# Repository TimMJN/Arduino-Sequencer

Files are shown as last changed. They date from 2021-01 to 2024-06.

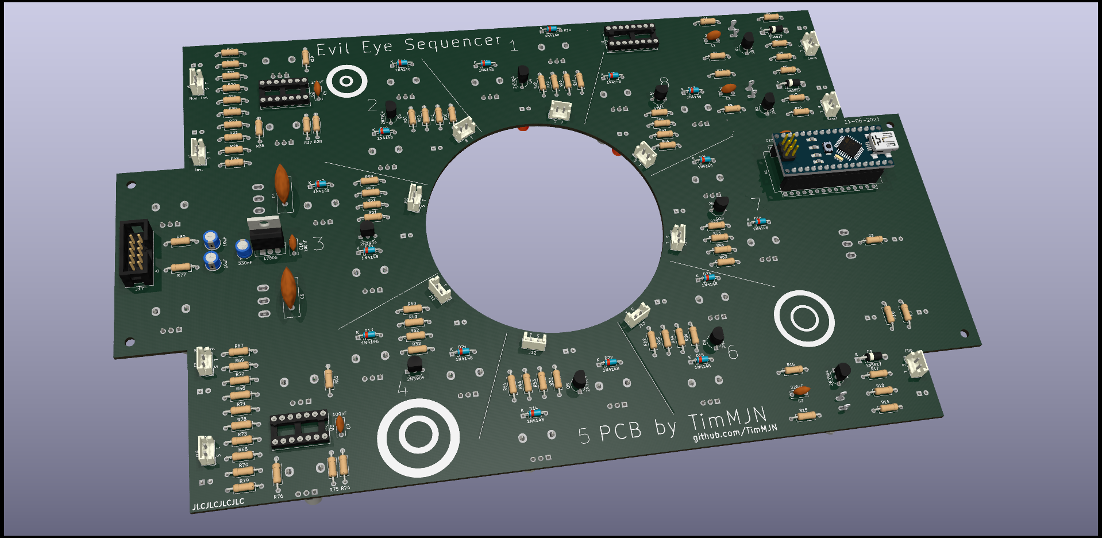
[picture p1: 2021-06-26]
images/arduino_sequencer_render_back.png

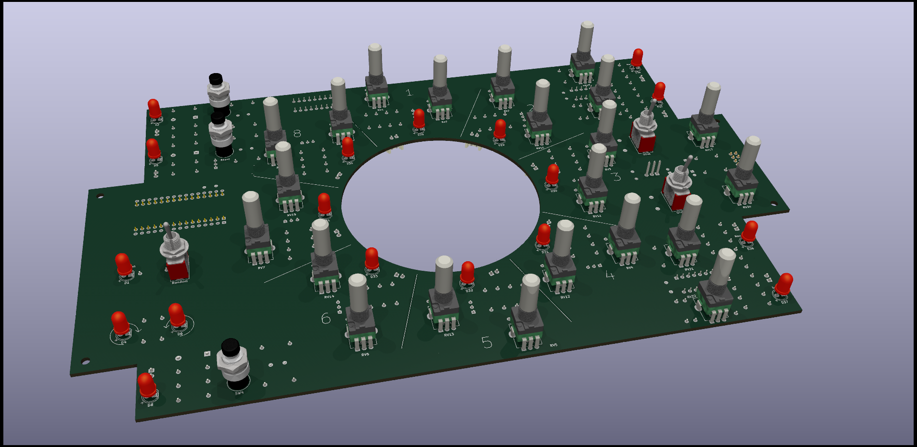
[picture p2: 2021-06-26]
images/arduino_sequencer_render_front.png

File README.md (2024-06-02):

# Arduino Sequencer
This projects contains schematics and firmware for a step sequencer compatible with Eurorack and Kosmo modular synthesizers, based on an Arduino Nano. This is a DIY project, suitable for beginners, although a general knowledge of electronics, basic tools and skills are required to build this sequencer. The schematics presented here feature:

- 8 steps, 2 voices
- Clock/reset/flip direction inputs
- Random sequence switch
- Buffered gate outputs per step
- Buffered CV outputs per voice
- Scale/offset controls
- Glide controls

Any builder is encouraged to experiment and make changed to the project to suit their needs. By the use of 74HC595 Serial-In-Parallel-Out shift registers to drive the step signals, this sequencer can be easily extended to 16, 32, 64 or even more steps. Similarly, additional voice can be easily added. I'll keep updating the project and documentation as I go.

A [short demonstration](https://youtu.be/yhleVjD8cbQ) is available in YouTube. View the [schematic](schematic+BOM/arduino_sequencer.pdf) and [bill of materials](https://htmlpreview.github.io/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) on this repository.

# Frequently Asked Questions
## The build
#### Do you have PCBs / panels available?
A PCB design for Kosmo format is available, along with a panel drill guide. I might have some PCBs available, please get in touch. However, it is also possible to build this design on perfboard/stripboard. I want to encourage any builder to come up with their own panel layout, make whatever feels natural to them. If you document your work, I'll be happy to add it here for future reference.

#### How to I add more steps?
Simply copy the main sequencer section as many times as you like. The connections between the 74HC595s are noted in the schematic. The latch and clock pins simply connect together, the serial out of each register connects to the serial in of the next. In the code, change the value of `N_STEPS` and voila!

#### How to I add more voices?
Copy the row of potentiometers/diodes in the main sequencer section as many times as you like. Don't forget to also copy the asociated output circuitry!

#### Can I leave out the gate buffers?
Yes you can. It would be best practice the keep them, but they could be replaced by just a protection diode (e.g. 1N1418).

#### Can I leave out the offset/scale/glide?
I would advice against using no buffering at all, but you could replace this section with just a unity gain buffer. It's also possible to leave out only the glide components, in which case you can also do without the non-inverting buffer behind it.

#### Can I leave out the input protection?
This I would strongly advice against. It's very easy to fry the Arduino by plugging in the wrong signal. You could simplify to a voltage clamp using two Schottky diodes, but I don't see the point in not doing it properly. If you do go with that option, don't forget to change to input logic to track rising instead of falling edges, as the current set-up inverts the inputs.

#### Can I leave out the randomise switch?
Yes, just simply don't include it.

## The code
#### Why don't you use `shiftOut`?
The serial output code I wrote here does the exact same thing as `shiftOut`. I only adapted it to output any number of steps, as the standard 8 bits by `shiftOut`.

#### What's this `interrupt` business?
This allows that Arduino to stop whatever it's doing when it receives a pulse on the clock input and update to the next step. That means that the polling of the other input pins will never slow down the progressing to the next step. Neat!

## The patch
#### Why can't I change the sequence length?
You can, simply patch the gate of the last step to the reset input.

#### Why can't I set a back-and-forth pattern?
You can, simply patch one or two of the gates to the flip input.

# License
All designs in this repository are released under GPL-3.0 licence. Feel free to use and adapt them to your heart's desire. I only ask to refrain from mass-production and commercialisation of PCBs/modules, as I rely on PCB sales for funding new module designs. If you use (parts of) my designs in your own modules, please credit me on your schematics and PCBs to help users find the original creator. I call upon your good conscience to make fair use of my work shared here.

# Support
If you like the resources I have made available here, and wish to support the development of new modules, feel free to buy me a few components through a small donation. I mainly design modules for fun, but you probably already know it can be a costly endeavour. All small contributions help me, thank you very much!



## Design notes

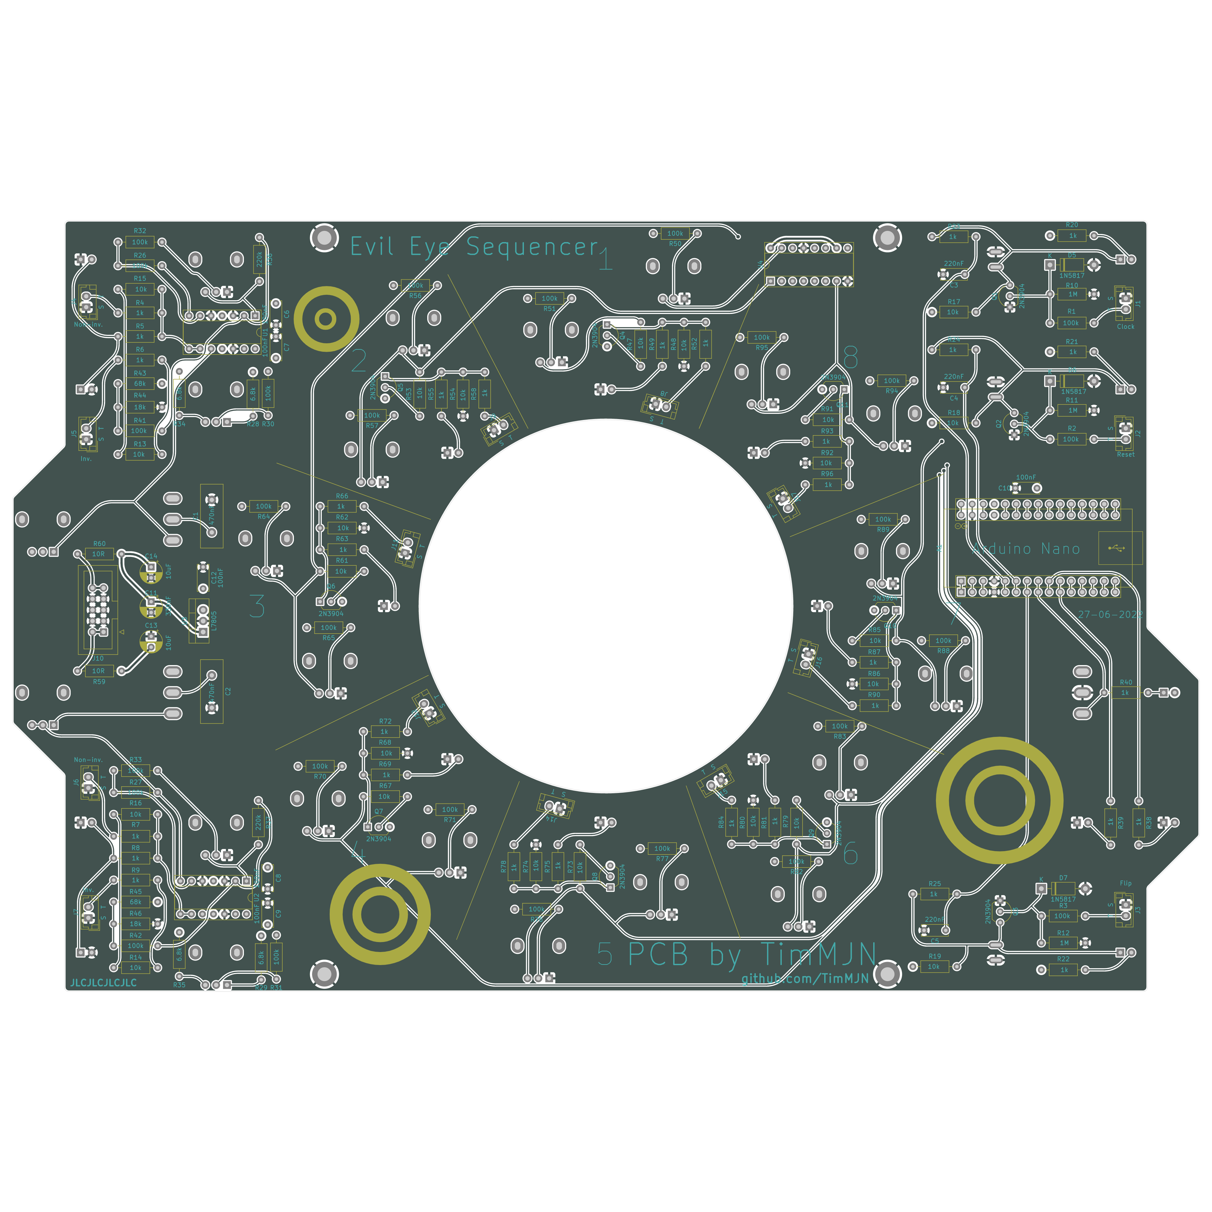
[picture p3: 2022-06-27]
PCB/arduino_sequencer-PCB_front.png

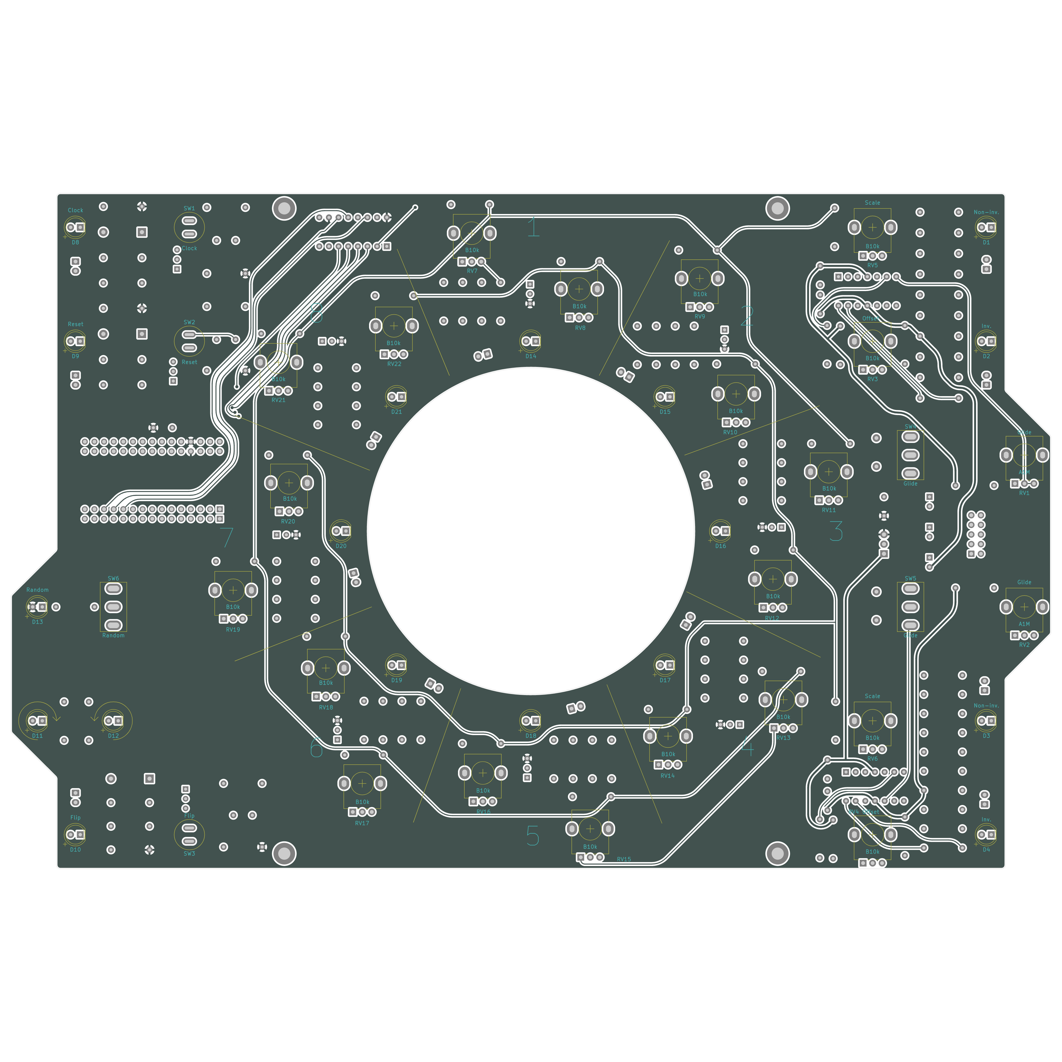
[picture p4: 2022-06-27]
PCB/arduino_sequencer-PCB_back.png

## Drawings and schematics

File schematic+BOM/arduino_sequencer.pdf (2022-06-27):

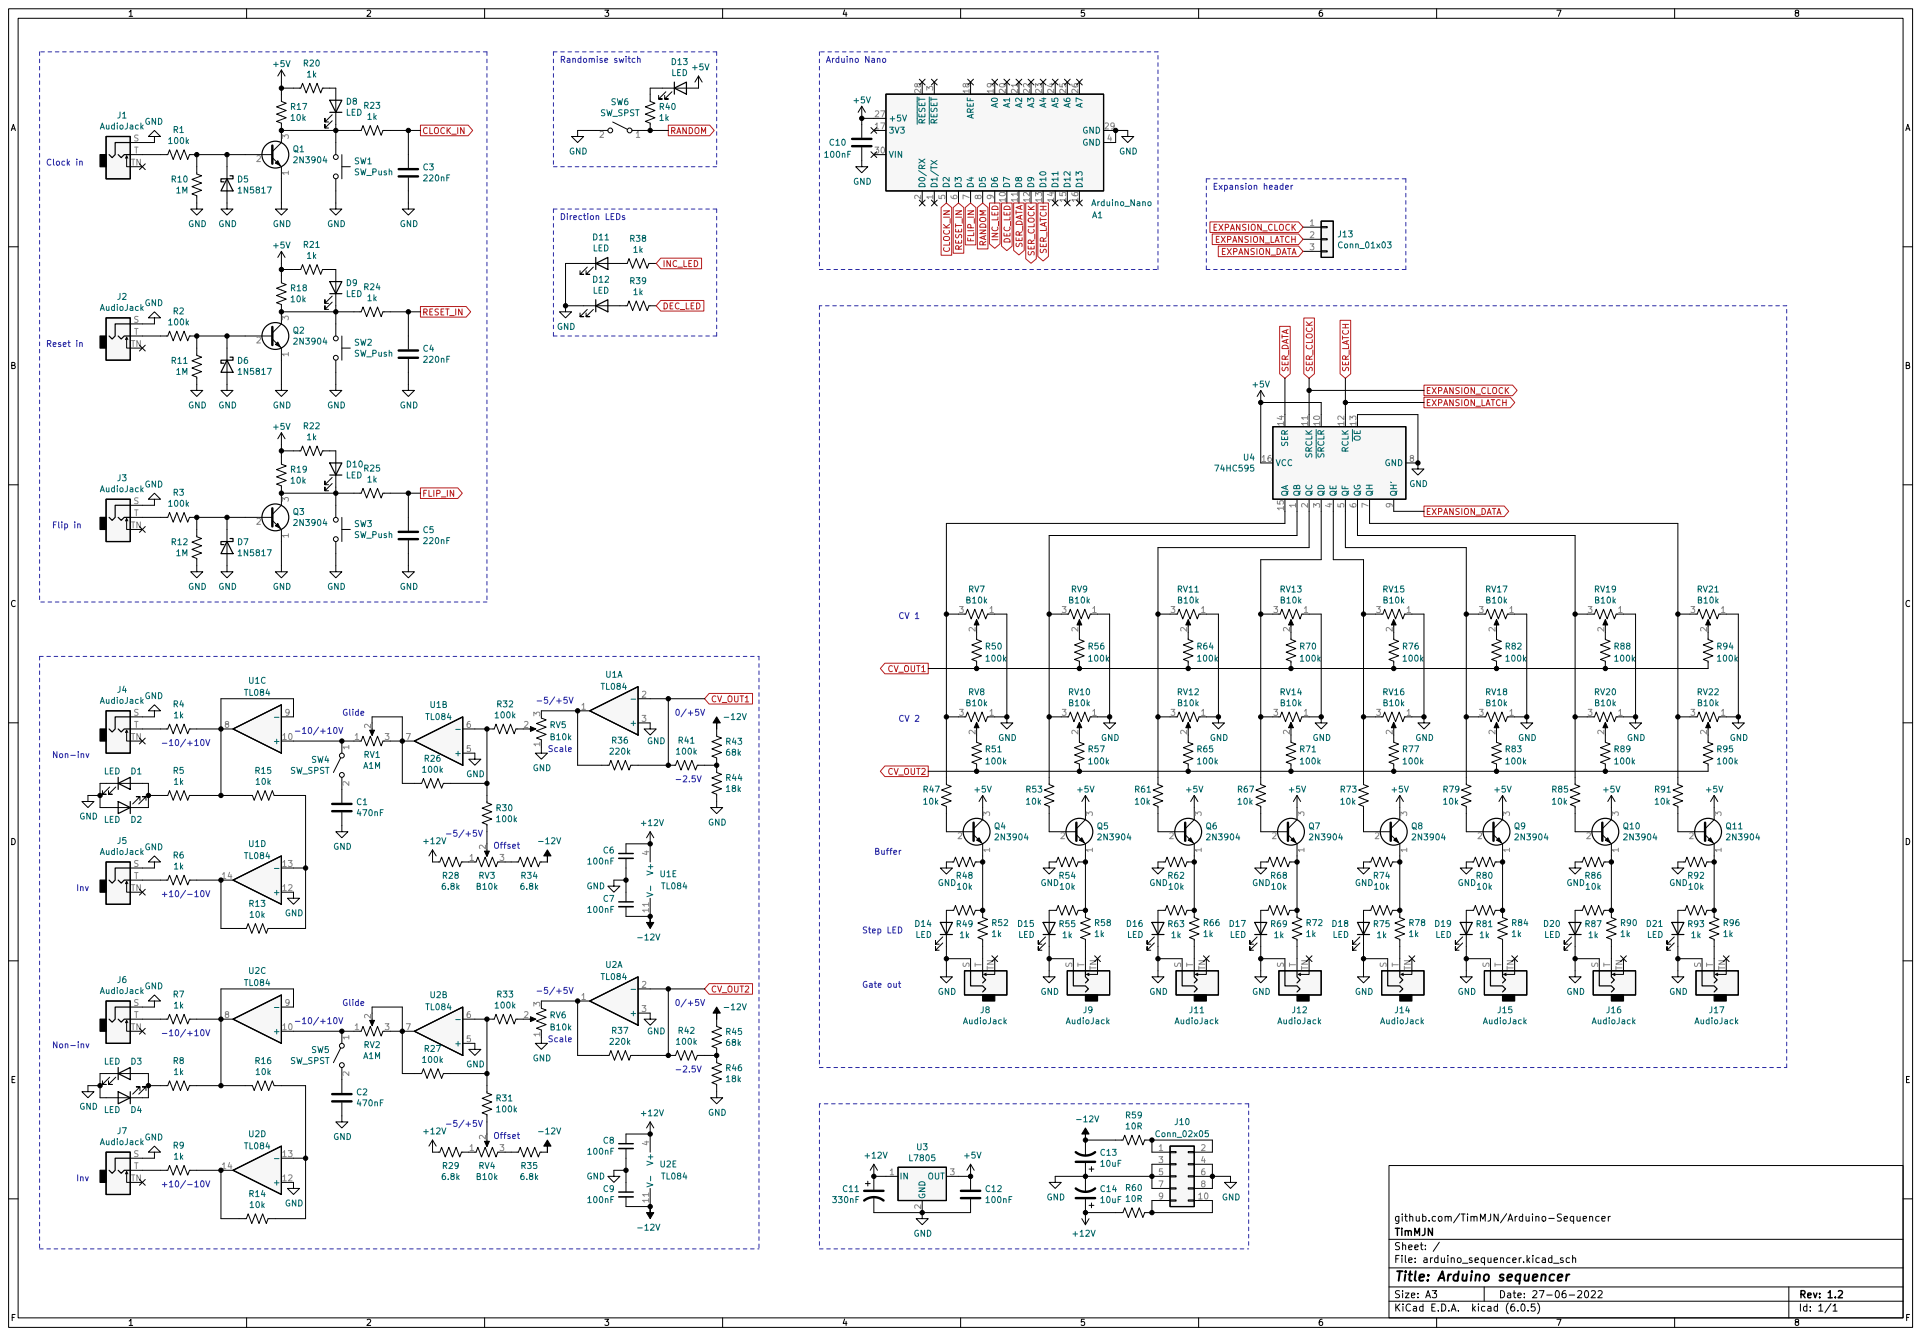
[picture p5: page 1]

Expansion header Non-inv

1 ~{SRCLR}10 SRCLK 11 RCLK 12 ~{OE}13 SER 14 QA 15 VCC 16 QC

github.com/TimMJN/Arduino-Sequencer D15

Id: 1/1 Title: Arduino sequencer

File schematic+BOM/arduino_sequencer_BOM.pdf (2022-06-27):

Arduino Sequencer | Rev: 1.4
TimMJN | 27-06-2022

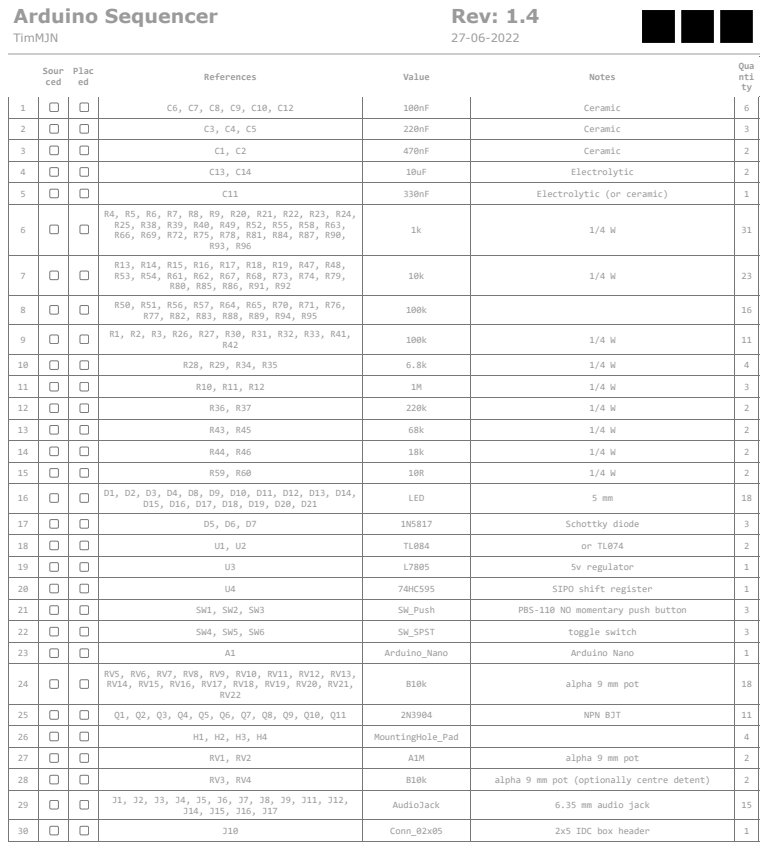
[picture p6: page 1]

Sour ced | Plac ed | References | Value | Notes | Qua nti ty

1 | | | C6, C7, C8, C9, C10, C12 | 100nF | Ceramic | 6

2 | | | C3, C4, C5 | 220nF | Ceramic | 3

3 | | | C1, C2 | 470nF | Ceramic | 2

4 | | | C13, C14 | 10uF | Electrolytic | 2

5 | | | C11 | 330nF | Electrolytic (or ceramic) | 1
6 | | | R4, R5, R6, R7, R8, R9, R20, R21, R22, R23, R24, R25, R38, R39, R40, R49, R52, R55, R58, R63, R66, R69, R72, R75, R78, R81, R84, R87, R90, R93, R96 | 1k | 1/4 W | 31

15 | | | R59, R60 | 10R | 1/4 W | 2
16 | | | D1, D2, D3, D4, D8, D9, D10, D11, D12, D13, D14, D15, D16, D17, D18, D19, D20, D21 | LED | 5 mm | 18

17 | | | D5, D6, D7 | 1N5817 | Schottky diode | 3

19 | | | U3 | L7805 | 5v regulator | 1

20 | | | U4 | 74HC595 | SIPO shift register | 1

21 | | | SW1, SW2, SW3 | SW_Push | PBS-110 NO momentary push button | 3

22 | | | SW4, SW5, SW6 | SW_SPST | toggle switch | 3

23 | | | A1 | Arduino_Nano | Arduino Nano | 1
24 | | | RV5, RV6, RV7, RV8, RV9, RV10, RV11, RV12, RV13, RV14, RV15, RV16, RV17, RV18, RV19, RV20, RV21, RV22 | B10k | alpha 9 mm pot | 18

25 | | | Q1, Q2, Q3, Q4, Q5, Q6, Q7, Q8, Q9, Q10, Q11 | 2N3904 | NPN BJT | 11

26 | | | H1, H2, H3, H4 | MountingHole_Pad | | 4

27 | | | RV1, RV2 | A1M | alpha 9 mm pot | 2

28 | | | RV3, RV4 | B10k | alpha 9 mm pot (optionally centre detent) | 2
29 | | | J1, J2, J3, J4, J5, J6, J7, J8, J9, J11, J12, J14, J15, J16, J17 | AudioJack | 6.35 mm audio jack | 15

30 | | | J10 | Conn_02x05 | 2x5 IDC box header | 1

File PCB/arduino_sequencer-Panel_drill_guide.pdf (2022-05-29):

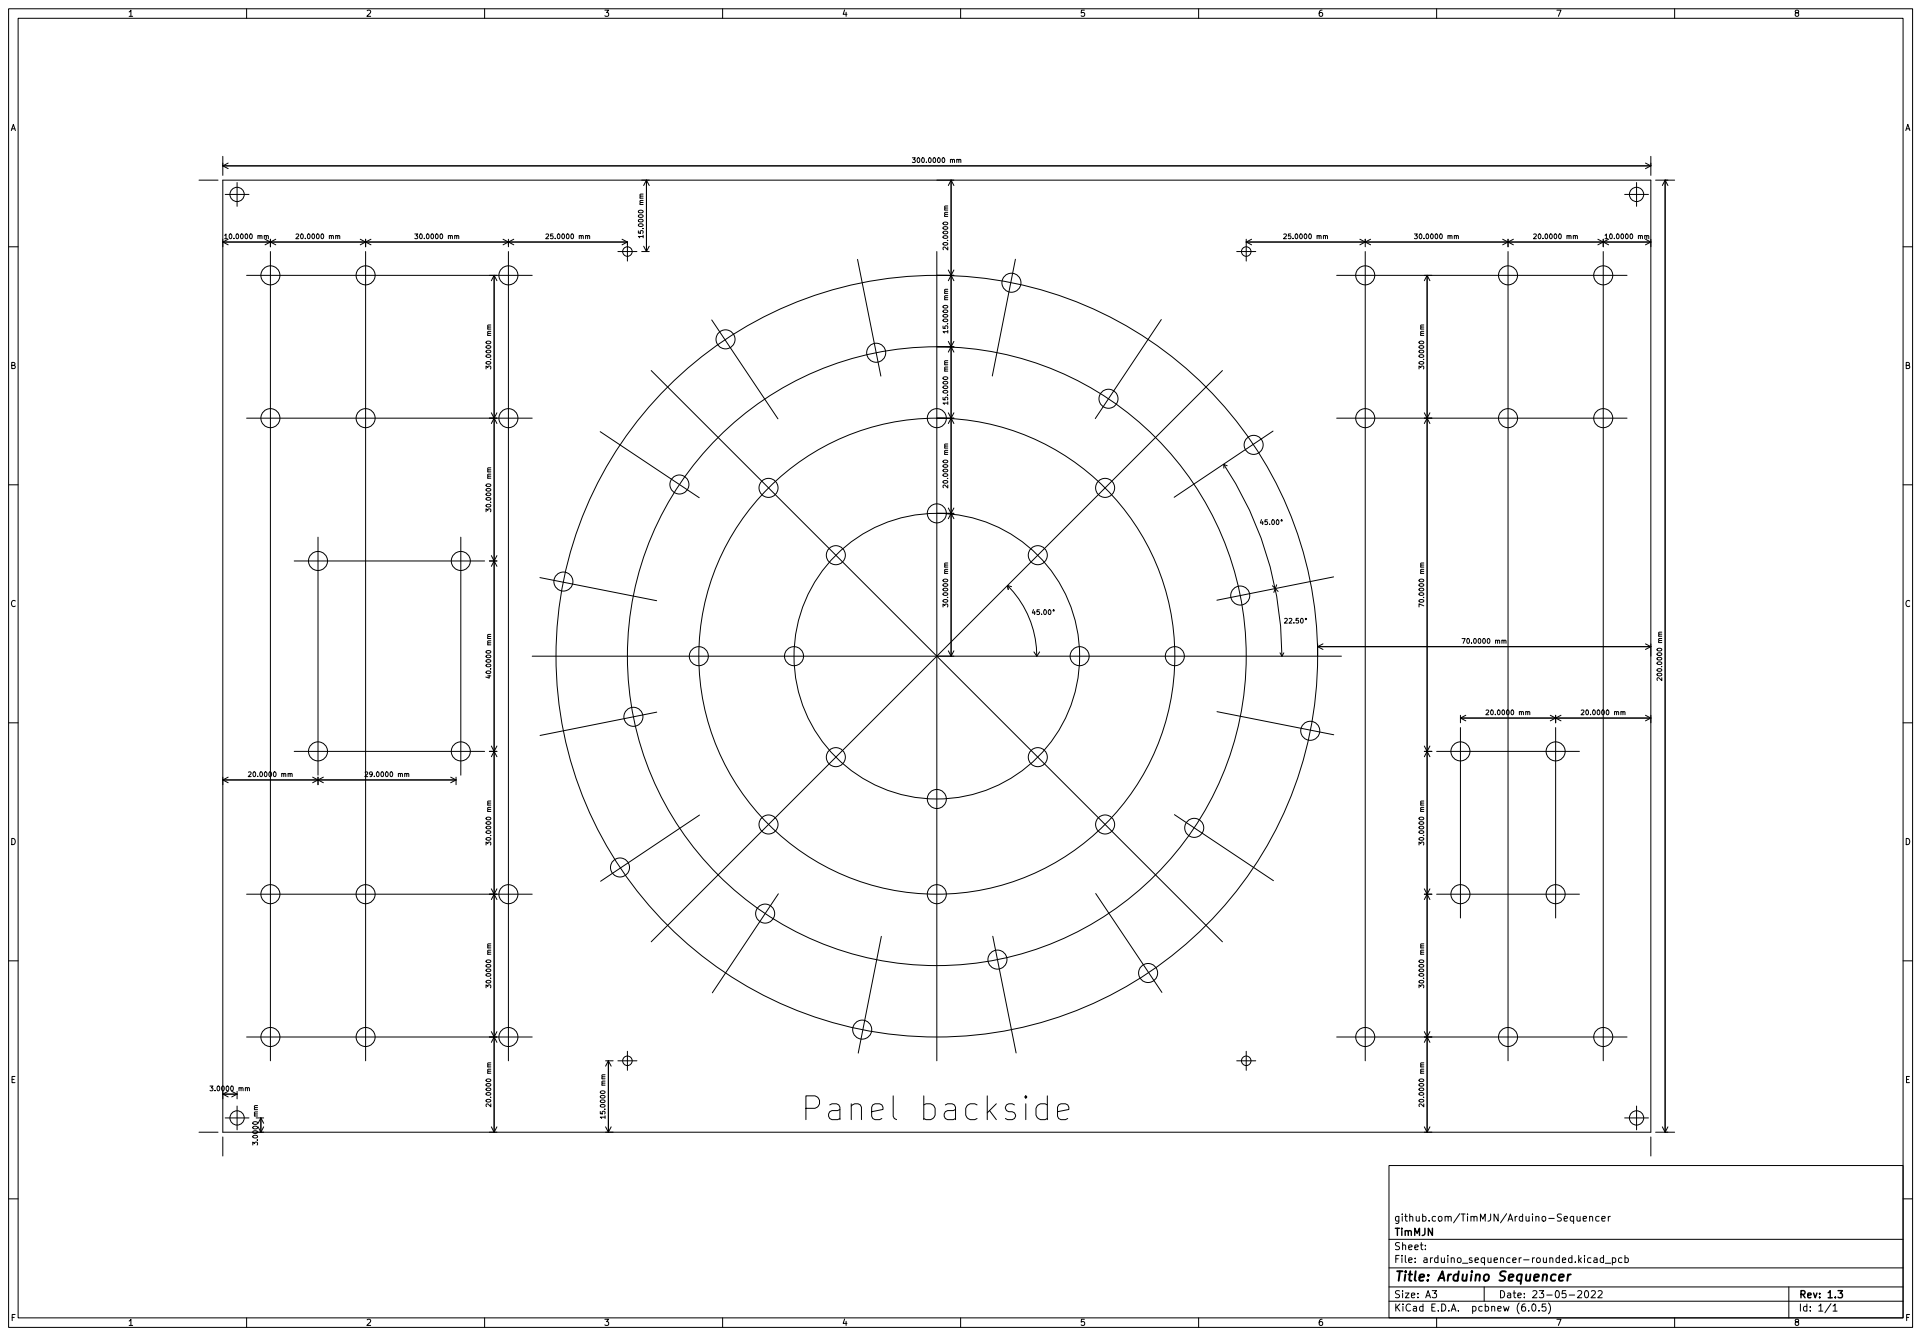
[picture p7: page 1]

github.com/TimMJN/Arduino-Sequencer
File: arduino_sequencer-rounded.kicad_pcb Sheet: TimMJN

Id: 1/1 Title: Arduino Sequencer

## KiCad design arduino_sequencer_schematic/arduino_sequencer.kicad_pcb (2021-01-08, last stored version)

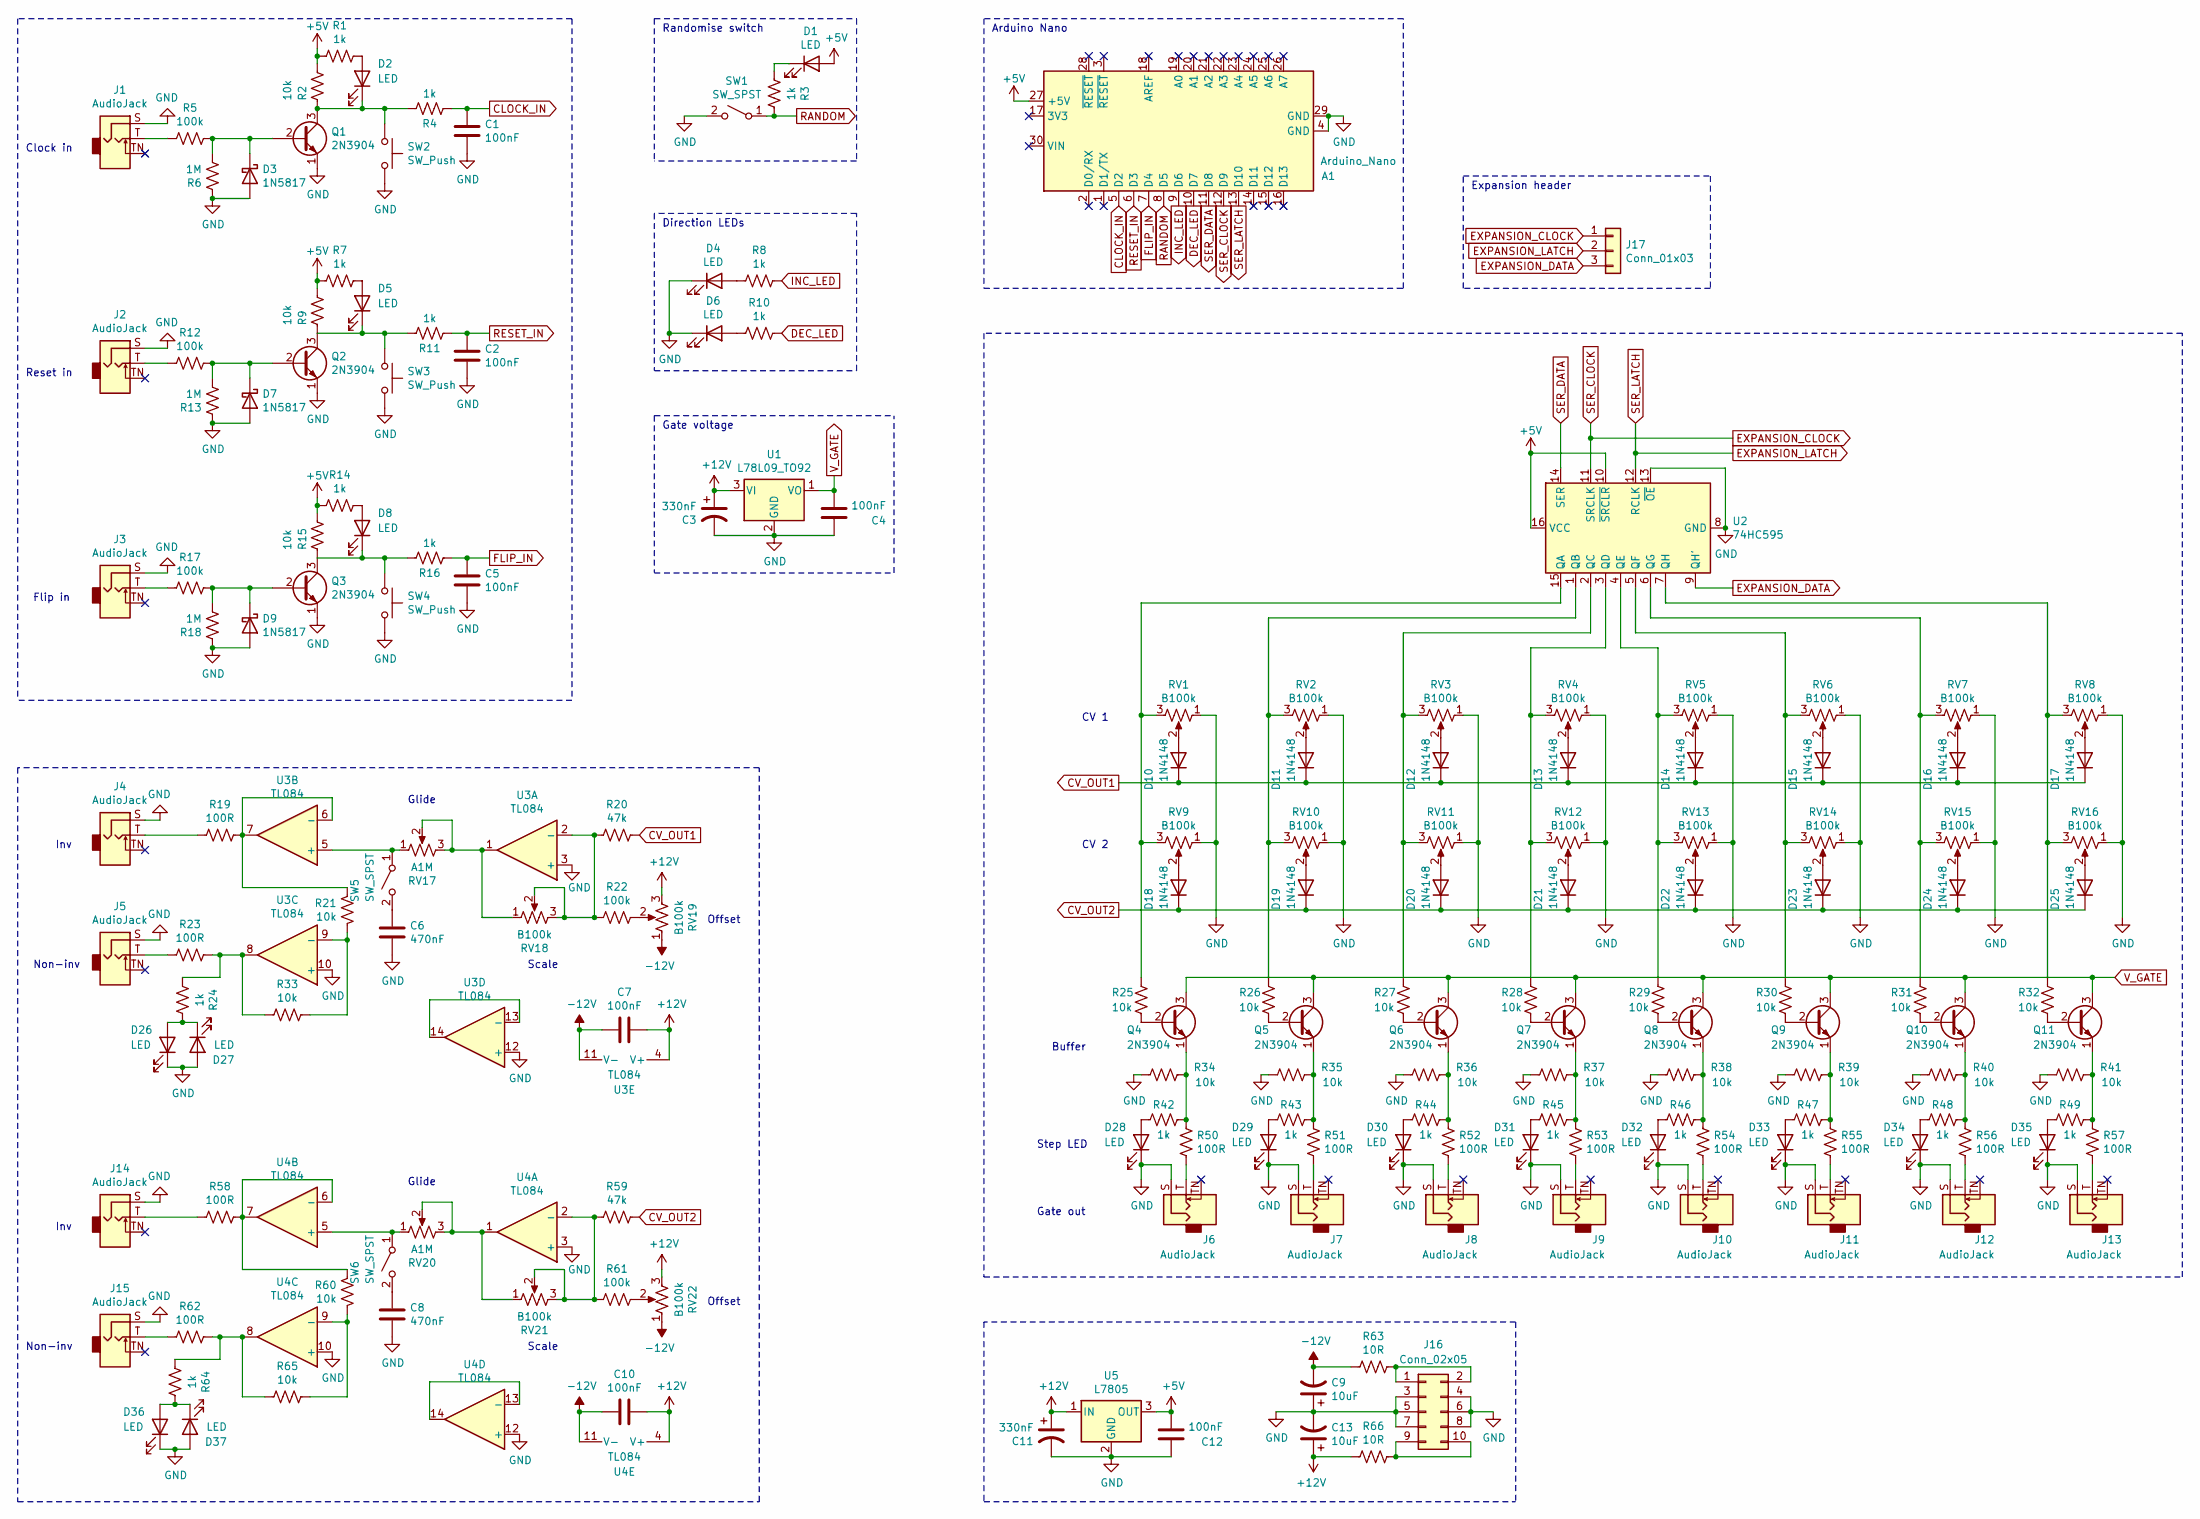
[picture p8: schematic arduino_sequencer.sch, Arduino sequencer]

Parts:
A1: Arduino_Nano; Arduino_Nano_2x_header
C1, C2, C4, C5, C7, C10, C12: 100nF; C_Disc_D6.0mm_W2.5mm_P5.00mm
C3, C11: 330nF; CP_Radial_D10.0mm_P3.80mm
C6, C8: 470nF; C_Disc_D14.5mm_W5.0mm_P7.50mm
C9, C13: 10uF; CP_Radial_D10.0mm_P3.80mm
D1, D2, D4, D5, D6, D8, D26, D27, D28, D29, D30, D31, D32, D33, D34, D35, D36, D37: LED; LED_D5.0mm
D3, D7, D9: 1N5817; D_DO-41_SOD81_P10.16mm_Horizontal
D10, D11, D12, D13, D14, D15, D16, D17, D18, D19, D20, D21, D22, D23, D24, D25: 1N4148; D_DO-35_SOD27_P7.62mm_Horizontal
J1, J2, J3, J4, J5, J6, J7, J8, J9, J10, J11, J12, J13, J14, J15: AudioJack; Jack_JST_conn_1x02_P2.50mm
J16: Conn_02x05; IDC-Header_2x05_P2.54mm_Vertical
J17: Conn_01x03; JST_EH_B3B-EH-A_1x03_P2.50mm_Vertical
Q1, Q2, Q3, Q4, Q5, Q6, Q7, Q8, Q9, Q10, Q11: 2N3904; TO-92_Inline
R1, R3, R4, R7, R8, R10, R11, R14, R16, R24, R42, R43, R44, R45, R46, R47, R48, R49, R64: 1k; R_Axial_DIN0207_L6.3mm_D2.5mm_P10.16mm_Horizontal_Value_Sil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
R2, R9, R15, R21, R25, R26, R27, R28, R29, R30, R31, R32, R33, R34, R35, R36, R37, R38, R39, R40, R41, R60, R65: 10k; R_Axial_DIN0207_L6.3mm_D2.5mm_P10.16mm_Horizontal_Value_Sil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
R5, R12, R17, R22, R61: 100k; R_Axial_DIN0207_L6.3mm_D2.5mm_P10.16mm_Horizontal_Value_Sil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
R6, R13, R18: 1M; R_Axial_DIN0207_L6.3mm_D2.5mm_P10.16mm_Horizontal_Value_Sil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
R19, R23, R50, R51, R52, R53, R54, R55, R56, R57, R58, R62: 100R; R_Axial_DIN0207_L6.3mm_D2.5mm_P10.16mm_Horizontal_Value_Sil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
R20, R59: 47k; R_Axial_DIN0207_L6.3mm_D2.5mm_P10.16mm_Horizontal_Value_Sil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
R63, R66: 10R; R_Axial_DIN0207_L6.3mm_D2.5mm_P10.16mm_Horizontal_Value_Sil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
RV1, RV2, RV3, RV4, RV5, RV6, RV7, RV8, RV9, RV10, RV11, RV12, RV13, RV14, RV15, RV16, RV18, RV19, RV21, RV22: B100k; Potentiometer_Alpha_RD901F-40-00D_Single_Vertical
RV17, RV20: A1M; Potentiometer_Alpha_RD901F-40-00D_Single_Vertical
SW1, SW5, SW6: SW_SPST; Switch_SP
SW2, SW3, SW4: SW_Push; Mom_push_button_PBS-110
U1: L78L09_TO92; TO-92_Inline
U2: 74HC595; DIP-16_W7.62mm
U3, U4: TL084; DIP-14_W7.62mm
U5: L7805; TO-220-3_Vertical

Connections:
+5V: A1.27 (+5V), C12.2, D1.2 (A), R1.2, R2.1, R7.2, R9.1, R14.2, R15.1, U2.10 (~SRCLR), U2.16 (VCC), U5.3 (OUT)
+12V: C3.1, C7.1, C10.1, C11.1, C13.1, R66.2, RV19.3, RV22.3, U1.3 (VI), U3.4 (V+), U4.4 (V+), U5.1 (IN)
-12V: C7.2, C9.2, C10.2, R63.2, RV19.1, RV22.1, U3.11 (V-), U4.11 (V-)
CLOCK_IN: A1.5 (D2), C1.1, R4.2
CV_OUT1: D10.1 (K), D11.1 (K), D12.1 (K), D13.1 (K), D14.1 (K), D15.1 (K), D16.1 (K), D17.1 (K), R20.1
CV_OUT2: D18.1 (K), D19.1 (K), D20.1 (K), D21.1 (K), D22.1 (K), D23.1 (K), D24.1 (K), D25.1 (K), R59.1
DEC_LED: A1.10 (D7), R10.1
EXPANSION_CLOCK: A1.12 (D9), J17.1, U2.11 (SRCLK)
EXPANSION_DATA: J17.3, U2.9 (QH')
EXPANSION_LATCH: A1.13 (D10), J17.2, U2.12 (RCLK)
FLIP_IN: A1.7 (D4), C5.1, R16.2
GND: A1.4 (GND), A1.29 (GND), C1.2, C2.2, C3.2, C4.1, C5.2, C6.2, C8.2, C9.1, C11.2, C12.1, C13.2, D3.2 (A), D4.1 (K), D6.1 (K), D7.2 (A), D9.2 (A), D26.1 (K), D27.2 (A), D28.1 (K), D29.1 (K), D30.1 (K), D31.1 (K), D32.1 (K), D33.1 (K), D34.1 (K), D35.1 (K), D36.1 (K), D37.2 (A), J1.S, J2.S, J3.S, J4.S, J5.S, J6.S, J7.S, J8.S, J9.S, J10.S, J11.S, J12.S, J13.S, J14.S, J15.S, J16.3, J16.4, J16.5, J16.6, J16.7, J16.8, Q1.1 (E), Q2.1 (E), Q3.1 (E), R6.1, R13.1, R18.1, R34.1, R35.1, R36.1, R37.1, R38.1, R39.1, R40.1, R41.1, RV1.1, RV2.1, RV3.1, RV4.1, RV5.1, RV6.1, RV7.1, RV8.1, RV9.1, RV10.1, RV11.1, RV12.1, RV13.1, RV14.1, RV15.1, RV16.1, SW1.2 (B), SW2.2, SW3.2, SW4.2, U1.2 (GND), U2.8 (GND), U2.13 (~OE), U3.3 (+), U3.10 (+), U3.12 (+), U4.3 (+), U4.10 (+), U4.12 (+), U5.2 (GND)
INC_LED: A1.9 (D6), R8.1
unnamed: C6.1, SW5.2 (B)
unnamed: C8.1, SW6.2 (B)
unnamed: D1.1 (K), R3.2
unnamed: D2.1 (K), Q1.3 (C), R2.2, R4.1, SW2.1
unnamed: D2.2 (A), R1.1
unnamed: D3.1 (K), Q1.2 (B), R5.1, R6.2
unnamed: D4.2 (A), R8.2
unnamed: D5.1 (K), Q2.3 (C), R9.2, R11.1, SW3.1
unnamed: D5.2 (A), R7.1
unnamed: D6.2 (A), R10.2
unnamed: D7.1 (K), Q2.2 (B), R12.1, R13.2
unnamed: D8.1 (K), Q3.3 (C), R15.2, R16.1, SW4.1
unnamed: D8.2 (A), R14.1
unnamed: D9.1 (K), Q3.2 (B), R17.1, R18.2
unnamed: D10.2 (A), RV1.2
unnamed: D11.2 (A), RV2.2
unnamed: D12.2 (A), RV3.2
unnamed: D13.2 (A), RV4.2
unnamed: D14.2 (A), RV5.2
unnamed: D15.2 (A), RV6.2
unnamed: D16.2 (A), RV7.2
unnamed: D17.2 (A), RV8.2
unnamed: D18.2 (A), RV9.2
unnamed: D19.2 (A), RV10.2
unnamed: D20.2 (A), RV11.2
unnamed: D21.2 (A), RV12.2
unnamed: D22.2 (A), RV13.2
unnamed: D23.2 (A), RV14.2
unnamed: D24.2 (A), RV15.2
unnamed: D25.2 (A), RV16.2
unnamed: D26.2 (A), D27.1 (K), R24.1
unnamed: D28.2 (A), R42.1
unnamed: D29.2 (A), R43.1
unnamed: D30.2 (A), R44.1
unnamed: D31.2 (A), R45.1
unnamed: D32.2 (A), R46.1
unnamed: D33.2 (A), R47.1
unnamed: D34.2 (A), R48.1
unnamed: D35.2 (A), R49.1
unnamed: D36.2 (A), D37.1 (K), R64.1
unnamed: J1.T, R5.2
unnamed: J2.T, R12.2
unnamed: J3.T, R17.2
unnamed: J4.T, R19.2
unnamed: J5.T, R23.2
unnamed: J6.T, R50.2
unnamed: J7.T, R51.2
unnamed: J8.T, R52.2
unnamed: J9.T, R53.2
unnamed: J10.T, R54.2
unnamed: J11.T, R55.2
unnamed: J12.T, R56.2
unnamed: J13.T, R57.2
unnamed: J14.T, R58.2
unnamed: J15.T, R62.2
unnamed: J16.1, J16.2, R63.1
unnamed: J16.9, J16.10, R66.1
unnamed: Q4.1 (E), R34.2, R42.2, R50.1
unnamed: Q4.2 (B), R25.2
unnamed: Q5.1 (E), R35.2, R43.2, R51.1
unnamed: Q5.2 (B), R26.2
unnamed: Q6.1 (E), R36.2, R44.2, R52.1
unnamed: Q6.2 (B), R27.2
unnamed: Q7.1 (E), R37.2, R45.2, R53.1
unnamed: Q7.2 (B), R28.2
unnamed: Q8.1 (E), R38.2, R46.2, R54.1
unnamed: Q8.2 (B), R29.2
unnamed: Q9.1 (E), R39.2, R47.2, R55.1
unnamed: Q9.2 (B), R30.2
unnamed: Q10.1 (E), R40.2, R48.2, R56.1
unnamed: Q10.2 (B), R31.2
unnamed: Q11.1 (E), R41.2, R49.2, R57.1
unnamed: Q11.2 (B), R32.2
unnamed: R19.1, R21.2, U3.6 (-), U3.7
unnamed: R20.2, R22.2, RV18.2, RV18.3, U3.2 (-)
unnamed: R21.1, R33.1, U3.9 (-)
unnamed: R22.1, RV19.2
unnamed: R23.1, R24.2, R33.2, U3.8
unnamed: R25.1, RV1.3, RV9.3, U2.15 (QA)
unnamed: R26.1, RV2.3, RV10.3, U2.1 (QB)
unnamed: R27.1, RV3.3, RV11.3, U2.2 (QC)
unnamed: R28.1, RV4.3, RV12.3, U2.3 (QD)
unnamed: R29.1, RV5.3, RV13.3, U2.4 (QE)
unnamed: R30.1, RV6.3, RV14.3, U2.5 (QF)
unnamed: R31.1, RV7.3, RV15.3, U2.6 (QG)
unnamed: R32.1, RV8.3, RV16.3, U2.7 (QH)
unnamed: R58.1, R60.2, U4.6 (-), U4.7
unnamed: R59.2, R61.2, RV21.2, RV21.3, U4.2 (-)
unnamed: R60.1, R65.1, U4.9 (-)
unnamed: R61.1, RV22.2
unnamed: R62.1, R64.2, R65.2, U4.8
unnamed: RV17.1, SW5.1 (A), U3.5 (+)
unnamed: RV17.2, RV17.3, RV18.1, U3.1
unnamed: RV20.1, SW6.1 (A), U4.5 (+)
unnamed: RV20.2, RV20.3, RV21.1, U4.1
unnamed: U3.13 (-), U3.14
unnamed: U4.13 (-), U4.14
RANDOM: A1.8 (D5), R3.1, SW1.1 (A)
RESET_IN: A1.6 (D3), C2.1, R11.2
SER_DATA: A1.11 (D8), U2.14 (SER)
V_GATE: C4.2, Q4.3 (C), Q5.3 (C), Q6.3 (C), Q7.3 (C), Q8.3 (C), Q9.3 (C), Q10.3 (C), Q11.3 (C), U1.1 (VO)

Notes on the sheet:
Offset
Scale
Glide
Inv
Non-inv
Gate out
Direction LEDs
Randomise switch
Clock in
Reset in
Flip in
Arduino Nano
Step LED
Buffer
CV 1
CV 2
Gate voltage
Expansion header

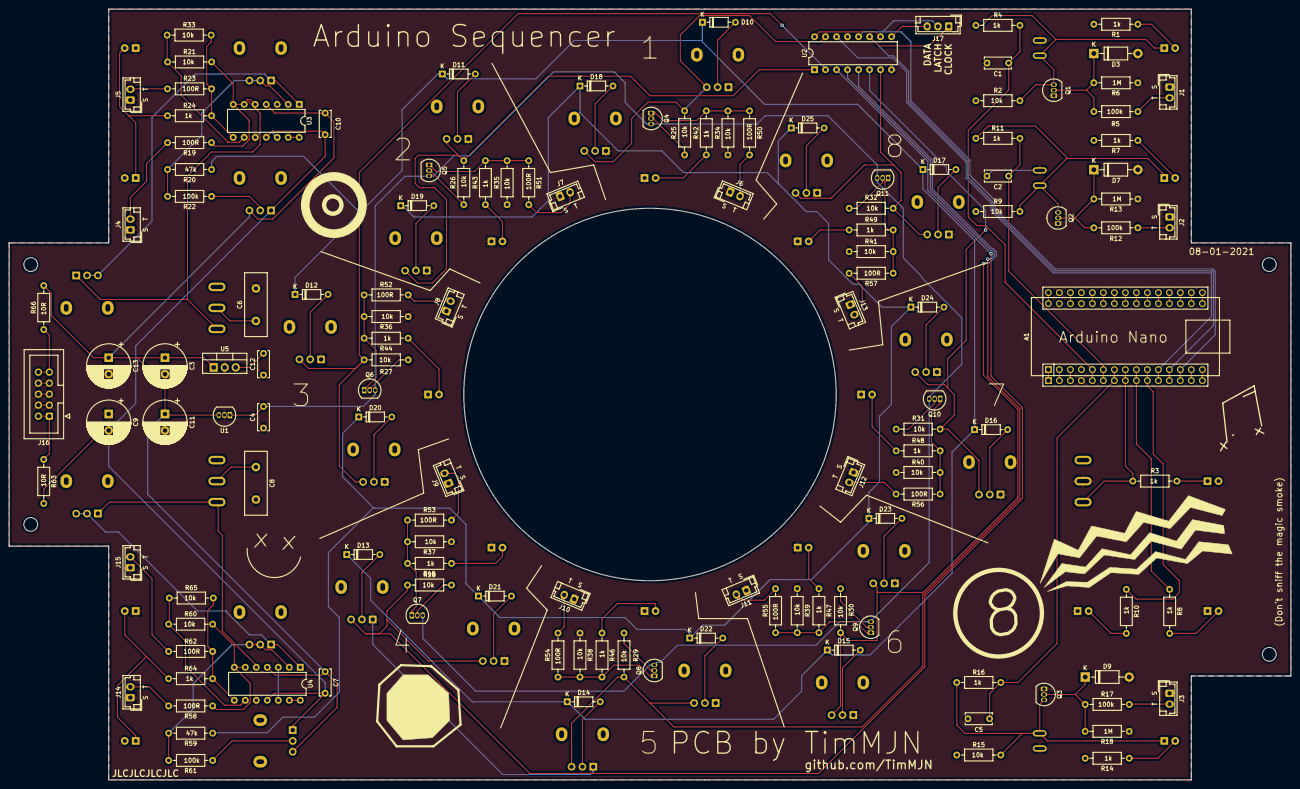
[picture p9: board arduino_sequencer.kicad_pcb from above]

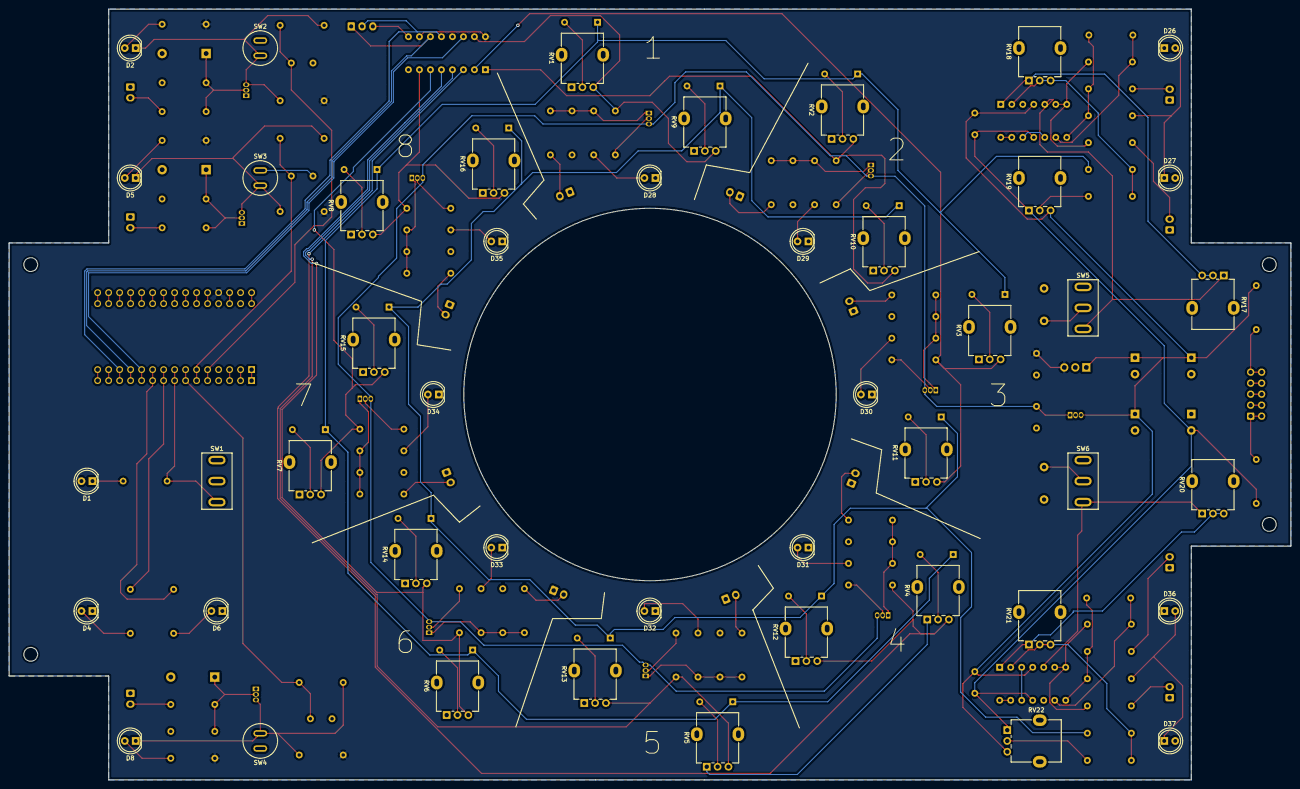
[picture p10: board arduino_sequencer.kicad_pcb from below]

Board: 2 copper layers, 296.0 x 178.0 mm, 178 parts (46 on the bottom side), 114 nets.

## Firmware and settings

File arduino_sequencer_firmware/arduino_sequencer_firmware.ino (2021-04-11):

////////////////////////////////////////////////////////////////////////////////////////////////////

/* 
 * Arduino Sequencer
 * synthesizer module firmware
 * 
 * by TimMJN
 * 
 * v1.0 
 * 16-01-2021
 * 
 * For schematics and other information, see
 * https://github.com/TimMJN/Arduino-Sequencer
 */

////////////////////////////////////////////////////////////////////////////////////////////////////

// pin definitions
#define CLOCK_PIN     2
#define RESET_PIN     3
#define FLIP_PIN      4
#define RAND_PIN      5
#define INC_LED_PIN   6
#define DEC_LED_PIN   7
#define SER_DATA_PIN  8
#define SER_CLOCK_PIN 9
#define SER_LATCH_PIN 10

#define N_STEPS 8 // number of steps

byte cur_step  = 0; // current step
byte next_step = 0; // next step
bool dir_inc   = true;  // direction (increasing = true, decreasing = false)
bool reset     = false; // has the reset been triggered this step?
bool randomise = false; // turn on/off random sequence

// current and previous states of reset and flip pins
bool cur_reset_state  = true;
bool prev_reset_state = true;
bool cur_flip_state   = true;
bool prev_flip_state  = true;
bool cur_rand_state   = true;
bool prev_rand_state  = true;

////////////////////////////////////////////////////////////////////////////////////////////////////

void setup() {
  // pin modes
  // alternatively ommit external pull up resistors and use INPUT_PULLUP
  pinMode(CLOCK_PIN,     INPUT);
  pinMode(RESET_PIN,     INPUT);
  pinMode(FLIP_PIN,      INPUT);
  pinMode(RAND_PIN,      INPUT_PULLUP);
  pinMode(INC_LED_PIN,   OUTPUT);
  pinMode(DEC_LED_PIN,   OUTPUT);
  pinMode(SER_DATA_PIN,  OUTPUT);
  pinMode(SER_CLOCK_PIN, OUTPUT);
  pinMode(SER_LATCH_PIN, OUTPUT);

  // set up interrupt on clock pin
  attachInterrupt(digitalPinToInterrupt(CLOCK_PIN), take_step, FALLING);
  interrupts();

  // set up randomisation
  randomise       = digitalRead(RAND_PIN) == LOW;
  prev_rand_state = digitalRead(RAND_PIN) == HIGH;

  // set next step and direction LEDs;
  set_next_step();
  set_direction_leds();

  // set output to first step
  set_shift_register(cur_step);
  digitalWrite(SER_LATCH_PIN, HIGH);

  // set shift register to next step
  set_shift_register(next_step);

  // do a small delay to prevent startup affecting inputs
  delay(100);
}

////////////////////////////////////////////////////////////////////////////////////////////////////

void loop() {
  // read reset and flip inputs
  cur_reset_state = digitalRead(RESET_PIN) == HIGH;
  cur_flip_state  = digitalRead(FLIP_PIN ) == HIGH;
  cur_rand_state  = digitalRead(RAND_PIN ) == HIGH;

  // edge detection on reset, flip and randomise inputs
  if (prev_reset_state && (!cur_reset_state)) {
    reset = true;
    set_next_step();
    set_shift_register(next_step); // update shift register
  }

  if (prev_flip_state && (!cur_flip_state)) {
    dir_inc = !dir_inc; // flip direction

    // update next step, shift register and LEDs
    set_next_step();
    set_shift_register(next_step); // update shift register
    set_direction_leds();
  }

  if (prev_rand_state && (!cur_rand_state)) { // turn on randomisation
    randomise = true;
    set_next_step();
    set_shift_register(next_step); // update shift register
  }
  if ((!prev_rand_state) && cur_rand_state) { // turn off randomisation
    randomise = false;
    set_next_step();
    set_shift_register(next_step); // update shift register
  }

  // update previous cycle values
  prev_reset_state = cur_reset_state;
  prev_flip_state  = cur_flip_state;
  prev_rand_state  = cur_rand_state;
}

////////////////////////////////////////////////////////////////////////////////////////////////////

// set what will be the next step
void set_next_step() {
  if (reset) {
    next_step = 0; // go back to step 0
  }
  else if (randomise) {
    next_step = random(0, N_STEPS); // pick a random step
  }
  else {
    if (dir_inc)
      next_step = (cur_step + 1) % N_STEPS; // increase 1 step
    else
      next_step = (cur_step - 1 + N_STEPS) % N_STEPS; // decrease 1 step
  }
}

////////////////////////////////////////////////////////////////////////////////////////////////////

// set the direction LEDs
void set_direction_leds() {
  if (dir_inc) {
    digitalWrite(INC_LED_PIN, HIGH);
    digitalWrite(DEC_LED_PIN, LOW);
  }
  else {
    digitalWrite(DEC_LED_PIN, HIGH);
    digitalWrite(INC_LED_PIN, LOW);
  }
}

////////////////////////////////////////////////////////////////////////////////////////////////////

// write the required state to the shift register
void set_shift_register(byte step_index) {
  noInterrupts(); // do not interrupt writing to the shift register

  // loop over the steps, starting from the last
  for (int i = (N_STEPS - 1); i >= 0; i--) {
    if (i == step_index)
      digitalWrite(SER_DATA_PIN, HIGH); // set current step high
    else
      digitalWrite(SER_DATA_PIN, LOW); // set other steps low
  
    digitalWrite(SER_CLOCK_PIN, HIGH); // give clock pin a pulse
    digitalWrite(SER_CLOCK_PIN, LOW);
  }

  interrupts(); // re-enable interrupts
}

////////////////////////////////////////////////////////////////////////////////////////////////////}

// interrupt function
// push shift register to output, prepare for the next step
void take_step() {
  // push to output register (pulse latch pin)
  digitalWrite(SER_LATCH_PIN, HIGH);
  digitalWrite(SER_LATCH_PIN, LOW);

  // update steps
  cur_step = next_step;
  reset = false;
  set_next_step();

  // update next step to shift register
  set_shift_register(next_step);
}

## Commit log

2020-12-08 Added schematics and firmware
    [arduino_sequencer.kicad_pcb, arduino_sequencer.sch]
2020-12-09 Chaged scale pot values to 50k
    [arduino_sequencer.sch]
2020-12-10 Fixed errors in CV interver and gate buffers
    [arduino_sequencer.sch]
2020-12-12 Changed negative input protection diodes to Schottky diodes
    [arduino_sequencer.sch]
2020-12-16 Fixed gate output resistors
    [arduino_sequencer.sch]
2020-12-18 Added additional LEDs
    [arduino_sequencer.sch]
2020-12-18 Added footprints
    [arduino_sequencer.sch]
2020-12-18 update PDF
    [arduino_sequencer.sch]
2020-12-19 started PCB layout
    [arduino_sequencer.kicad_pcb]
2020-12-19 Changed gate voltage to 9V by default
    [arduino_sequencer.kicad_pcb, arduino_sequencer.sch]
2020-12-19 PCB update
2020-12-28 Update arduino_sequencer.kicad_pcb
    PCB updates
    [arduino_sequencer.kicad_pcb]
2020-12-30 added missing GND label
    [arduino_sequencer.sch]
2020-12-30 Added expansion header
    [arduino_sequencer.sch]
2020-12-30 PCB routed
    [arduino_sequencer.kicad_pcb]
2021-01-03 Footprint updates
    [arduino_sequencer.kicad_pcb]
2021-01-03 Added resistor values on silkscreen
    [arduino_sequencer.kicad_pcb, arduino_sequencer.sch]
2021-01-03 fixed arduino reset/flip pin inconsistency
    [arduino_sequencer.kicad_pcb, arduino_sequencer.sch]
2021-01-03 Move filter resistor
    For improved stability (no faulty triggers)
    [arduino_sequencer.kicad_pcb, arduino_sequencer.sch]
2021-01-03 moved lowering of latch pin to interrupt
2021-01-07 Finetuned gain/offset ranges
    [arduino_sequencer.kicad_pcb, arduino_sequencer.sch]
2021-01-07 Date update
    [arduino_sequencer.kicad_pcb]
2021-01-07 Fixed potentiometer directions
    [arduino_sequencer.kicad_pcb, arduino_sequencer.sch]
2021-01-08 prepare for production
    [arduino_sequencer.kicad_pcb]
2021-01-08 added BOM
2021-01-08 added panel drill guide
2021-01-08 Pull all KiCad files
    I've decided to remove all KiCad files from the repository, in order to keep the design a bit more in my own hands. I will continue publishing schematics and layouts as PDFs, so anyone can reproduce 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
    [arduino_sequencer.kicad_pcb, arduino_sequencer.sch]
2021-01-09 Added PCB layout files
2021-01-19 PCB updates
2021-03-05 removed 9V supply
2021-03-09 schematic cleanup
2021-04-24 Added decoupling cap to Arduino
2021-04-24 BOM update
2021-06-08 moved pcb files
2021-08-19 added interactive BOM
2021-11-28 added dimensions to drill guide
2022-05-29 update PCB files
2022-05-29 remove old PCB files
2022-06-27 schematic update
    switch from diodes to resistors for adding cvs, replace B200k pot with B10k
